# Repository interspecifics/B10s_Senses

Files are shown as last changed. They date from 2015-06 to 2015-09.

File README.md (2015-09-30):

# Open Sensory Substitution by Interspecifics

The term sensory substitution refers to a non-invasive technique introduced by neuroscientist Paul Bach-y-Rita in the 60's who attends restoring senses damaged using hybrid interfaces brain-machine to redirect certain characteristics of a sensory modality to another and using the adaptive capacities of the brain to replace perceptual categories. He suggests that while the brain and its connection with the environment operate properly, peripheral sensory systems are secondary in the exercise of global cognition.

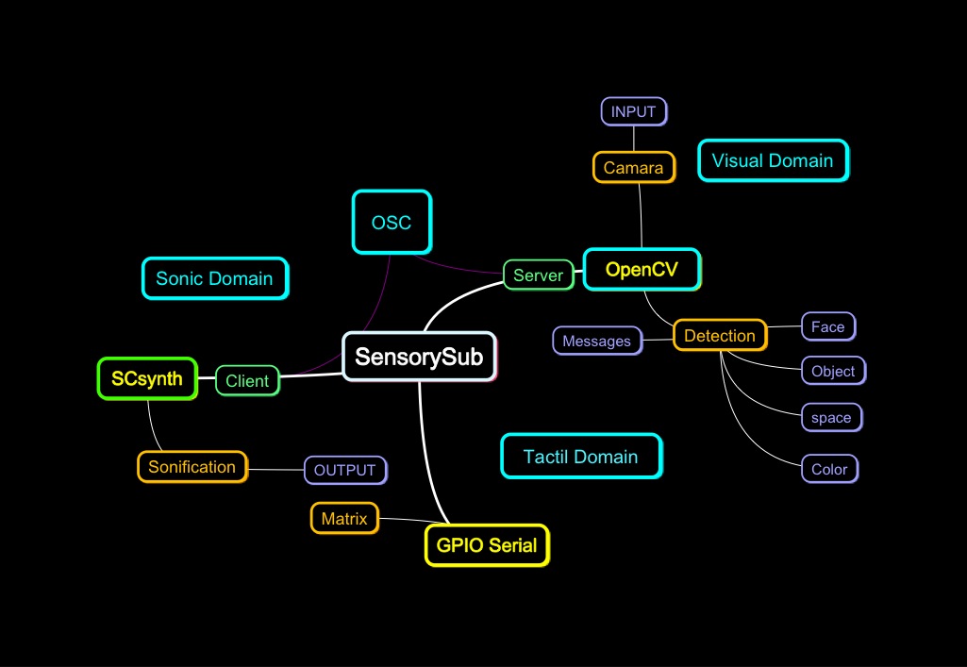
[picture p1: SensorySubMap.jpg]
the system


The aim of the prototype of sensory substitution is to allow the brain to create a mapping of space through sound and electrotáctiles sensations. And thus consider expanding human capabilities and challenge the Aristotelian conception that postulates five senses with specific functions clearly separated from each other.

In this project we are using OpenCV to detect blobs from a video camara attached to the Raspberry Pi, this detections is later tranform into sound using SuperCollider and SC.VO.3.1 for python and electrical impulses using GPIOS.

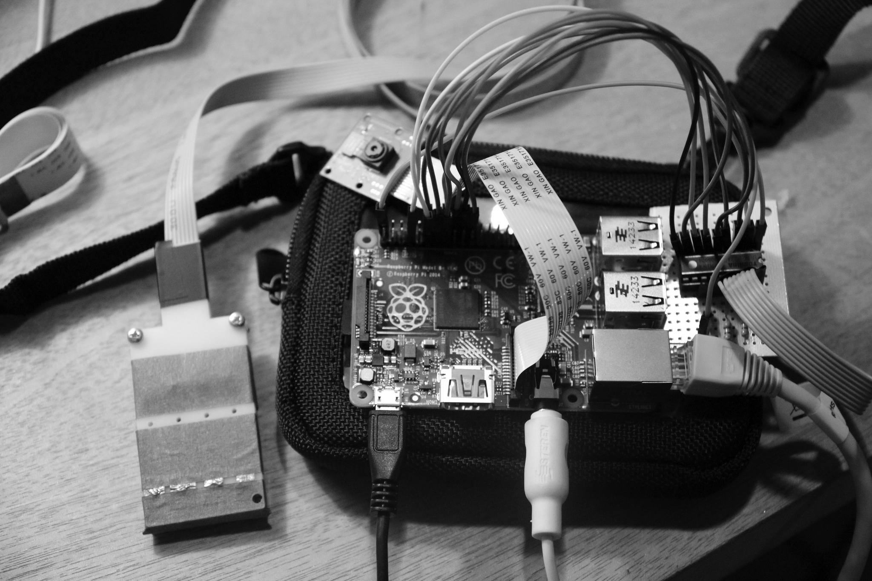
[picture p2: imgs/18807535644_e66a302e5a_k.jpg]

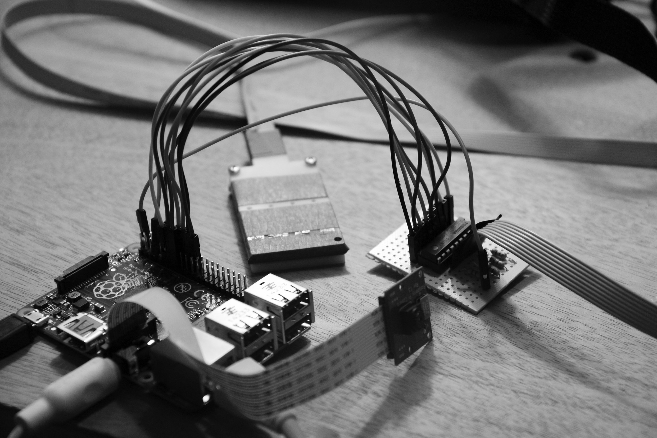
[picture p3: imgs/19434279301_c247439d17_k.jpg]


# HARDWARE:
- RaspberryPi B+
- Camara module for raspberry 
- Micro sd cards  
- Electro-tactil transducers 
- Lithium baterrys for the raspberry 

# RASPBIAN IMAGE WITH LIBRARIES AND CODE:
The following image contains all the libraries necessary to round the OSS, incluiding the python scripts to comunicate OpenCV with SuperCollider. 

- http://interspecifics.cc/downloads/OSSraspi.dmg

#Libraries and installs

- OpenCV for python 
  http://docs.opencv.org/index.html
OpenCV (Open Source Computer Vision Library) is an open source computer vision and machine learning software library. OpenCV was built to provide a common infrastructure for computer vision applications and to accelerate the use of machine perception in the commercial products. Being a BSD-licensed product, OpenCV makes it easy for businesses to utilize and modify the code.

- SuperCollider: 
  http://supercollider.github.io/development/building-raspberrypi.html
SuperCollider is a programming language for real time audio synthesis and algorithmic composition.
The language interpreter runs in a cross platform IDE (OS X/Linux/Windows) and communicates via Open Sound Control with one or more synthesis servers. The SuperCollider synthesis server runs in a separate process or even on a separate machine so it is ideal for realtime networked music.

- SC.V0.3.1 
  http://www.ixi-software.net/content/download/sc/sc-0.3.1.zip
The scosc module converts standard python types to supercollider osc messages.
In order to play sounds in musical time, we have to send OSC messages with timestamps. Because the server has a limited message buffer (1024), we have to send messages as a stream in real-time. The challenge is getting the messages in early enough that the server can process them, while not sending too many as to override the buffer. We also have to take latency into account, which makes this a much bigger bundle of fun.

#HOW TO RUN THE SOFTWARE

- $ ssh pi@sensory1.local
- $ password: 1234
- $ cd B10s_Senses
- $ cd B10s_Senses/Python 
- $ cd B10s_Senses/Python/examples 
- $ cd ..
- $ cd B10s_Senses/Python
- $ ./prepServer.sh 
- $ sudo python b10sOpenCv.py

#Python + SuperCollider examples

In the following example with show a regular synthdef from supercollider using the sclang lenguage:

___________________________
 ```
(
SynthDef("PMCrotale", {
arg midi = 60, tone = 3, art = 1, amp = 0.8, pan = 0;
var env, out, mod, freq;
freq = midi.midicps;
env = Env.perc(0, art);
mod = 5 + (1/IRand(2, 6));
out = PMOsc.ar(freq, mod*freq,
	pmindex: EnvGen.kr(env, timeScale: art, levelScale: tone),
	mul: EnvGen.kr(env, timeScale: art, levelScale: 0.3));
out = Pan2.ar(out, pan);
out = out * EnvGen.kr(env, timeScale: 1.3*art,
	levelScale: Rand(0.1, 0.5), doneAction:2);
Out.ar(0, out); //Out.ar(bus, out);
}).add;
)

Synth("PMCrotale", ["midi", rrand(48, 72).round(1), "tone", rrand(1, 6)])
 ```
In this case we invoque using a regular synth argument.

___________________________

Using python tu interface:
 ```
import sc
import time, random

seed = random.Random()

sc.start( verbose=1, spew=1 )
s = sc.sc.server ###################

PMCrotale = sc.Synth( "PMCrotale" )
PMCrotale.freq = 400

timeout = time.time() + 10 # 10 secs

while time.time() < timeout :
    time.sleep(0.5) # loop every half sec
    PMCrotale.midi = seed.randint( 40, 90 )
    PMCrotale.tono =  10
    PMCrotale.art = 1

PMCrotale.free()
sc.quit()

print 'seeya world! ...........'

 ```
#FUTURE DEVELOPMENTS:

The following maps were designed during the workshop of sensory substitution in the UDK Berlin. The idea to expand the possibilities of the system in search of a systematic process that also allows sensory expansion.

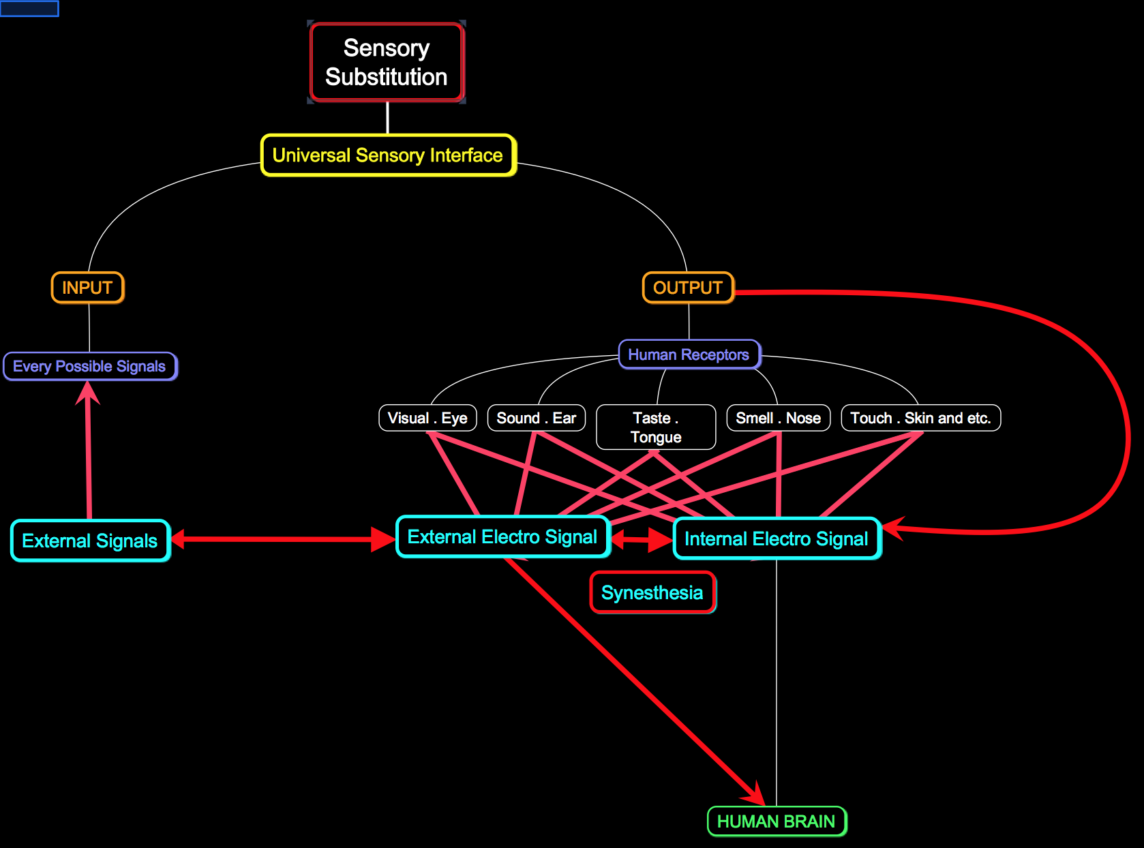
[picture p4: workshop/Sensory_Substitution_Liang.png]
uNIVERSAL

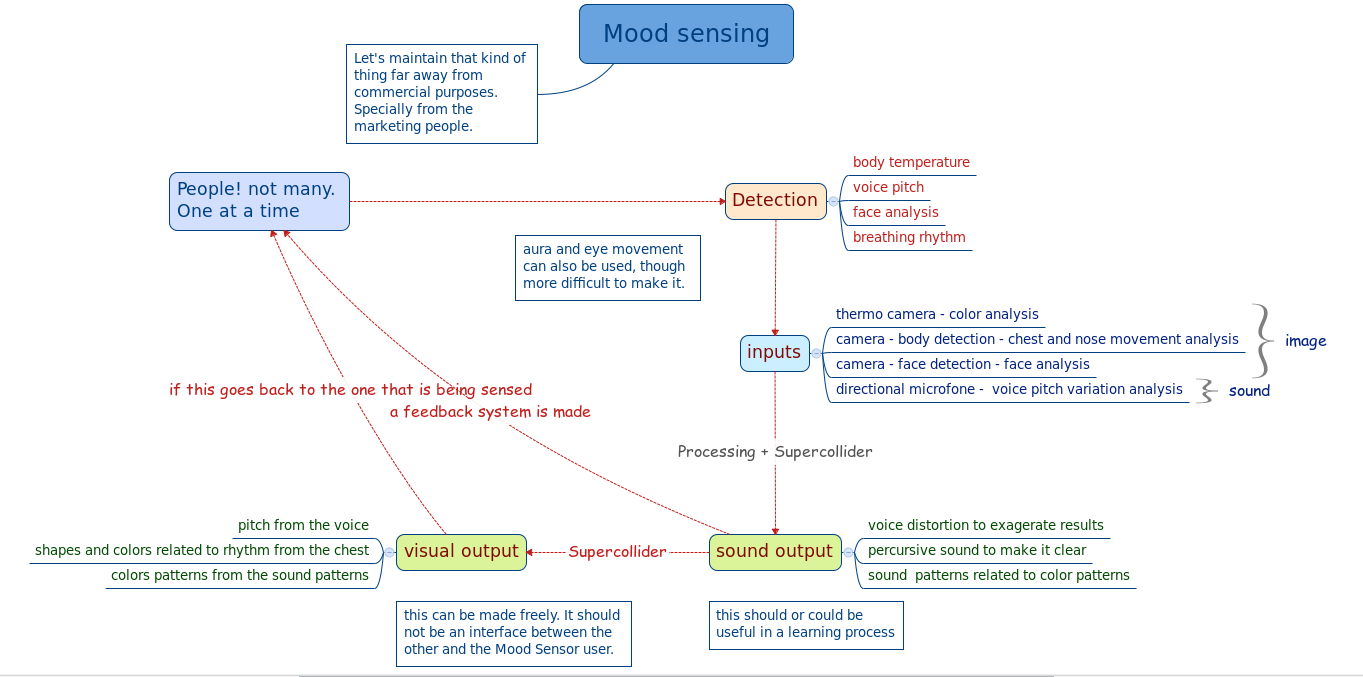
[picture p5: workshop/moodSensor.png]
mood


#TEAM
- Paloma López
- Leslie García
- Thiago Hersan

info[at]interspecifics.cc

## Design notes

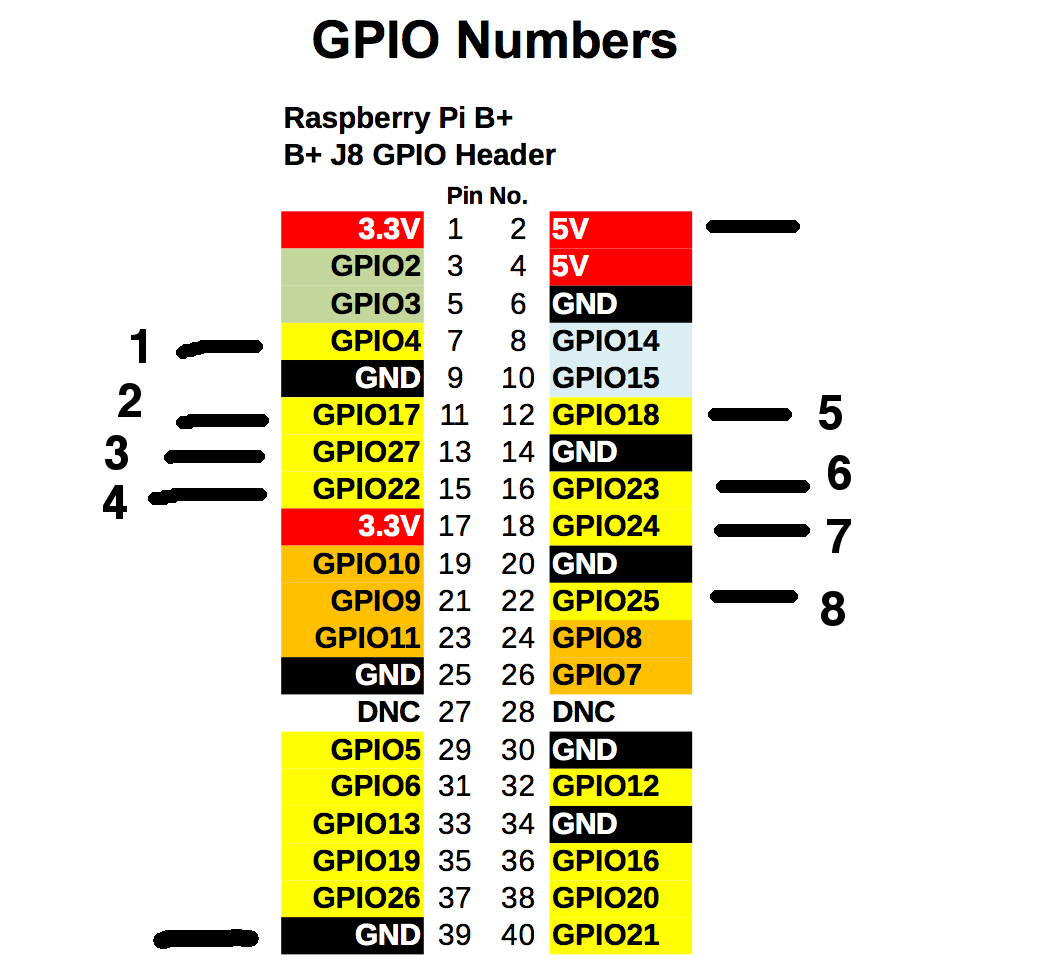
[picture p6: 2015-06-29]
imgs/B10s_RaspberryPi-GPIOpinout.png

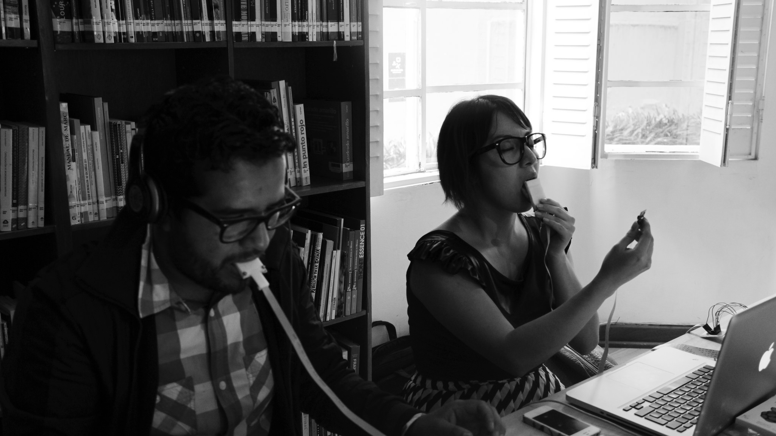
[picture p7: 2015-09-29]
imgs/19423771112_f4510b2ece_k.jpg

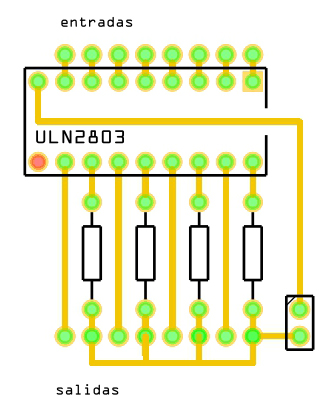
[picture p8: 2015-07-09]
imgs/sensorysub_pcb.jpg

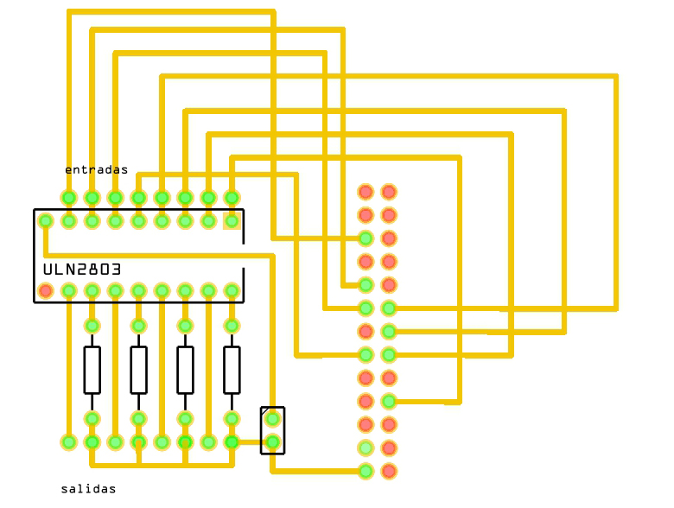
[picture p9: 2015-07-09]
imgs/sensorysub_pcbPin.jpg

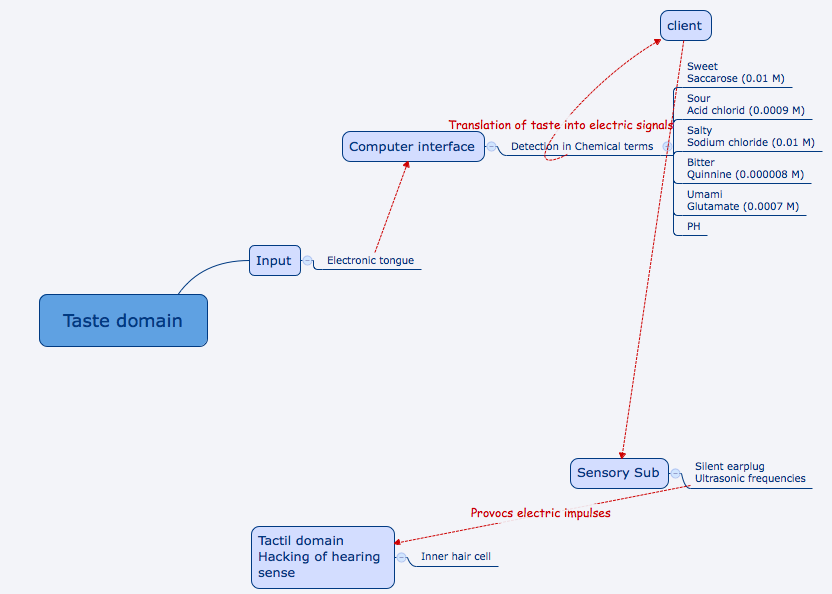
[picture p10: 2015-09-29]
workshop/tasteSensor.png

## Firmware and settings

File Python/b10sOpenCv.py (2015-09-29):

#!/usr/bin/env python

import cv2
import sys, time
import numpy as np
import sc
from threading import Thread
from Camera import Camera

try:
    import RPi.GPIO as GPIO
except Exception as e:
    class GPIO():
        BCM = 0
        OUT = 0
        @staticmethod
        def setmode(sp):
            pass
        @staticmethod
        def setup(p, v):
            pass
        @staticmethod
        def cleanup():
            pass
        @staticmethod
        def output(p, v):
            pass

FPS = 20.0
LOOP_PERIOD = 1.0/FPS

CAM_RES = (160, 120)

TENS_FREQ = 80
TENS_PERIOD = 1.0/TENS_FREQ

POWS = (4,27,18,24)
GPIOS = (17,22,23,25)
TENS_LEN = len(GPIOS)
powVals = [1]*TENS_LEN
gpioVals = [0]*TENS_LEN

(SB,XB,YB) = (0,0,0)
(SH,XH,YH) = (0,0,0)
cascadeDetected = 0
blobDetected = 0
FPA = 0.5
FPB = 1.0-FPA

def setup():
    global prevFrame, frame, mCamera
    global mDetector, mCascade
    global POWS, GPIOS, powVals, gpioVals
    global mSynth

    sc.start()
    mSynth = sc.Synth("fmSynth")
    #mSynth = sc.Synth("PMCrotale")

    GPIO.setmode(GPIO.BCM)
    for pin in (POWS+GPIOS):
        GPIO.setup(pin, GPIO.OUT)

    mCamera = Camera(CAM_RES)
    mCamera.update()

    frame = cv2.blur(cv2.cvtColor(mCamera.frame, cv2.COLOR_RGB2GRAY), (4,4))
    prevFrame = frame

    # Setup SimpleBlobDetector parameters.
    mParams = cv2.SimpleBlobDetector_Params()
    mParams.minThreshold = 16;
    mParams.maxThreshold = 32;
    mParams.filterByArea = True
    mParams.minArea = 64
    mParams.maxArea = 10e3
    mParams.filterByConvexity = True
    mParams.minConvexity = 0.001
    mParams.filterByInertia = True
    mParams.minInertiaRatio = 0.001

    mDetector = cv2.SimpleBlobDetector(mParams)
    mCascade = None

    if len(sys.argv) > 1:
        mCascade = cv2.CascadeClassifier(sys.argv[1])
    else:
        print "Please provide a cascade file if you want to do face/body detection."

def loop():
    global prevFrame, frame, mCamera
    global mDetector, mCascade
    global POWS, GPIOS, powVals, gpioVals
    global SH,XH,YH, SB,XB,YB, cascadeDetected, blobDetected
    global mSynth

    prevFrame = frame

    mCamera.update()

    frameU = cv2.cvtColor(mCamera.frame, cv2.COLOR_RGB2GRAY)
    frame = cv2.blur(frameU, (4,4))
    diffFrame = cv2.absdiff(frame, prevFrame)

    ret, diffFrameThresh = cv2.threshold(diffFrame, 32, 255, cv2.THRESH_BINARY_INV)
    blobs = []
    blobs = mDetector.detect(diffFrameThresh)

    powVals = [1]*TENS_LEN
    gpioVals = [0]*TENS_LEN

    (s,x,y) = (0,0,0)
    blobDetected *= 0.9
    numBlobs = len(blobs)
    # average blobs
    for blob in blobs:
        (s,x,y) = (s+blob.size, x+blob.pt[0], y+blob.pt[1])

    if (numBlobs > 0):
        (s,x,y) = ((s/numBlobs), x/numBlobs, y/numBlobs)
        (SB,XB,YB) = (FPA*SB+FPB*s, FPA*XB+FPB*x, FPA*YB+FPB*y)
        # set up pulses
        (XBN, YBN) = (XB/CAM_RES[0], YB/CAM_RES[1])
        pulseLocationIndex = int(XBN*2)+2*int(YBN*2)
        powVals[pulseLocationIndex] = 0
        gpioVals[pulseLocationIndex] = 1

        #set up Synth
        mSynth.freq1 = 150*XBN+250
        mSynth.freq2 = 5*YBN+1
        blobDetected = 10.0

        #another Synth
        #mSynth.midi = XBN
        #mSynth.art = 1*YBN
        #mSynth.tone = 6*XBN+4

    mSynth.amp = blobDetected

    if mCascade is not None:
        cascadeResult = []
        if (time.time()%5 > 4):
            cascadeResult = mCascade.detectMultiScale(
                frameU,
                scaleFactor=1.1,
                minNeighbors=5,
                minSize=(16, 16),
                flags=cv2.cv.CV_HAAR_SCALE_IMAGE)

        # get cascade detector results and update (size, x, y)
        cascadeDetected *= 0.8
        (s,x,y) = (0,0,0)
        if len(cascadeResult) > 0:
            cascadeDetected = 2.0
        for (x0, y0, w0, h0) in cascadeResult:
            if(w0 > s):
                (s,x,y) = (w0, x0, y0)
        if cascadeDetected > 1.0:
            (SH,XH,YH) = (FPA*SH+FPB*s, FPA*XH+FPB*x, FPA*YH+FPB*y)

    # Display the resulting frame
    #cv2.imshow('_', cv2.drawKeypoints(diffFrameThresh, blobs, np.array([]), (0,0,255), cv2.DRAW_MATCHES_FLAGS_DRAW_RICH_KEYPOINTS))

    if cv2.waitKey(1) & 0xFF == ord('q'):
        cleanUp()
        sys.exit(0)

def cleanUp():
    global mCamera, mSynth
    mSynth.free()
    sc.quit()
    mCamera.release()
    GPIO.cleanup()
    cv2.destroyAllWindows()

if __name__=="__main__":
    lastLoop = 0
    tensWaveVal = 0
    calcTens = True

    def upTWV():
        global tensWaveVal
        while(calcTens is True):
            tensWaveVal = int((time.time()/TENS_PERIOD)%2)
            time.sleep(TENS_PERIOD)

    t = Thread(target=upTWV)
    t.start()
    setup()
    try:
        while True:
            GPIO.output(POWS, tuple([tensWaveVal*v for v in powVals]))
            GPIO.output(GPIOS, tuple([tensWaveVal*v for v in gpioVals]))

            now = time.time()
            if (now-lastLoop > LOOP_PERIOD):
                lastLoop = now
                loop()
                print "%s"%(1.0/(time.time()-lastLoop))
    except Exception as e:
        print e
        cleanUp()
        calcTens = False
        time.sleep(1)
        t.join(1)

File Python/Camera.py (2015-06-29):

import cv2
import time

try:
    from picamera.array import PiRGBArray
    from picamera import PiCamera

except Exception as e:
    class Camera():
        def __init__(self, (xdim, ydim)):
            self.video_capture = cv2.VideoCapture(0)
            self.video_capture.set(3,xdim)
            self.video_capture.set(4,ydim)
        def update(self):
            self.frame = self.video_capture.read()[1]
        def release(self):
            self.video_capture.release()

else:
    class Camera():
        def __init__(self, (xdim, ydim)):
            self.mCamera = PiCamera()
            self.mCamera.resolution = (xdim, ydim)
            self.mCamera.framerate = 16
            self.mStream = PiRGBArray(self.mCamera)
            time.sleep(2.0)
        def update(self):
            self.mStream.truncate(0)
            self.mCamera.capture(self.mStream, format="bgr", use_video_port=True)
            self.frame = self.mStream.array
        def release(self):
            pass

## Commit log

2015-06-15 gerber files for tongue matrix circuit
    [sensorysub_contour.gm1, sensorysub_copperBottom.gbl, sensorysub_copperTop.gtl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]
2015-06-15 Basi python sensory server
2015-06-22 using tuple for pin list to output to all channels at once
2015-06-22 fixes list initialization bug
    [testGPIO.py]
2015-06-23 new pin assignments for new electrode arrangement
2015-06-23 with pi camera
2015-06-23 fixes bug. adds osc message declarations
    [b10sOpenCv.py]
2015-06-24 cleans up globals and adds gpio pin initialization
2015-06-24 adds thread for generating the tens vals
2015-06-24 fixes threading
2015-06-24 adds pulse location based on camera blob
2015-06-24 fixes bug of using non-normalized coordinates ot index array
    [b10sOpenCv.py]
2015-06-25 combines pi and mac version into one, with a modular Camera class
2015-06-25 avoids copying frame array
    [Camera.py, b10sOpenCv.py]
2015-06-25 imports time into Camera
2015-06-25 fixes slow rpi camera. uses video_port. duh
    [Camera.py]
2015-06-25 makes sure the prepServer stuff doesn't run as root
    [b10sOpenCv.py]
2015-07-09 circuit images
